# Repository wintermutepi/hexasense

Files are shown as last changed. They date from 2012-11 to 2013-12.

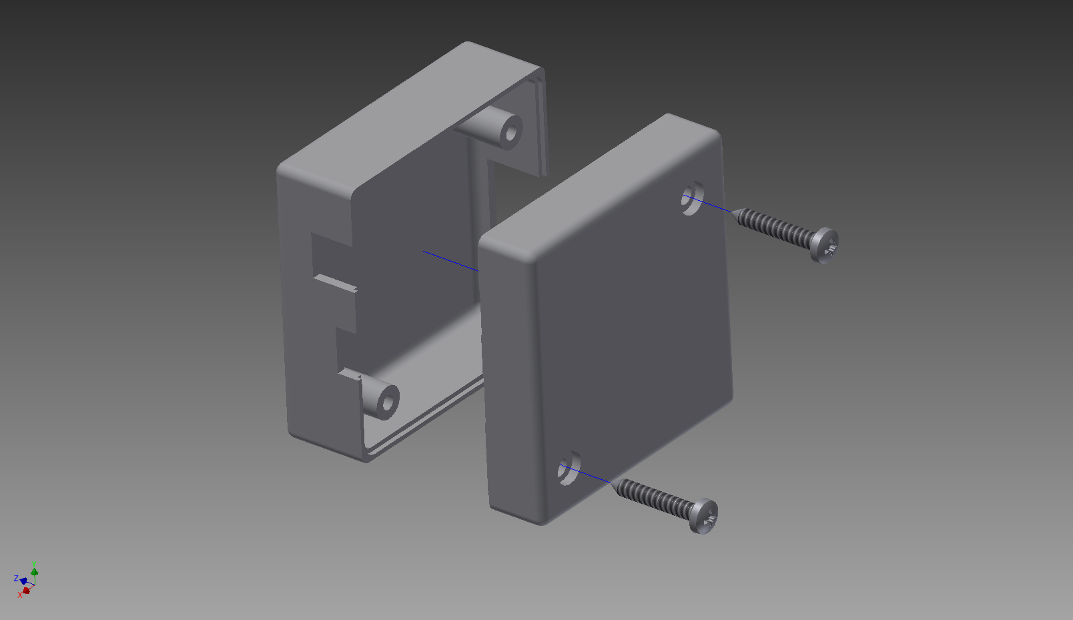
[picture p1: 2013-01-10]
enclosure/power_board/Assembly1.png

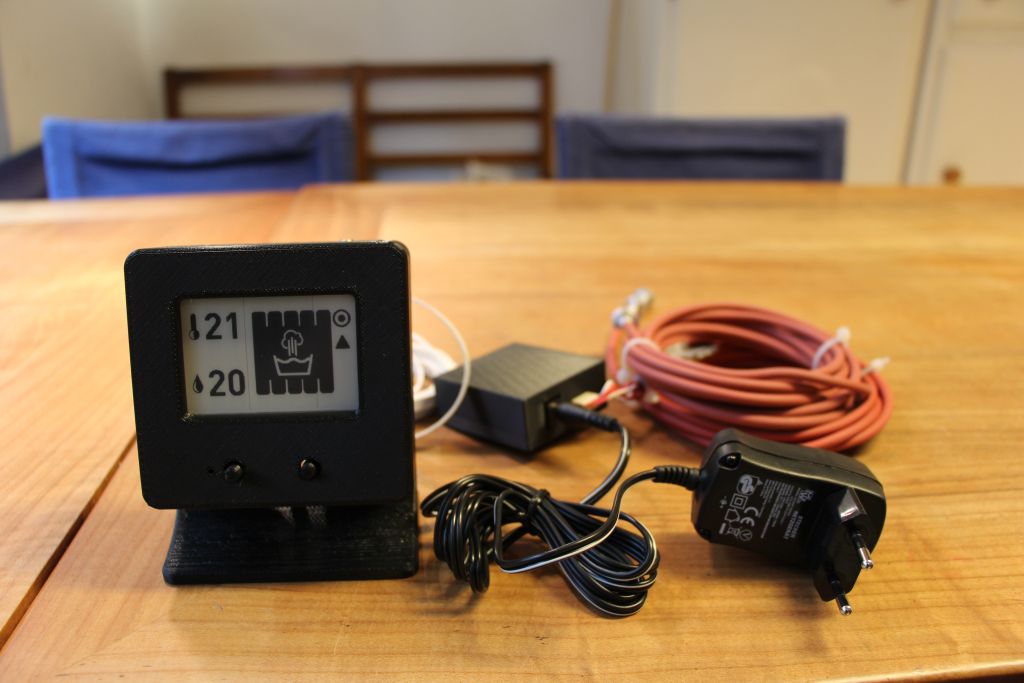
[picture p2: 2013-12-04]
doc/IMG_2463_.jpg

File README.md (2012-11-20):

HexaSense
=========

This is a prototyping project for a room heating controller based on the
HexaBus architecture. Nothing spectacular to see here - this is just a
playground.

### License

The UART code is written by Peter Fleury. Everything else: BSD 2-clause
license as below:

Copyright (c) 2012, Mathias Dalheimer
All rights reserved.

Redistribution and use in source and binary forms, with or without
modification, are permitted provided that the following conditions are
met:

* Redistributions of source code must retain the above copyright notice, 
this list of conditions and the following disclaimer.

* Redistributions in binary form must reproduce the above copyright
notice, this list of conditions and the following disclaimer in the
documentation and/or other materials provided with the distribution.

THIS SOFTWARE IS PROVIDED BY THE COPYRIGHT HOLDERS AND CONTRIBUTORS "AS
IS" AND ANY EXPRESS OR IMPLIED WARRANTIES, INCLUDING, BUT NOT LIMITED
TO, THE IMPLIED WARRANTIES OF MERCHANTABILITY AND FITNESS FOR A
PARTICULAR PURPOSE ARE DISCLAIMED. IN NO EVENT SHALL THE COPYRIGHT
HOLDER OR CONTRIBUTORS BE LIABLE FOR ANY DIRECT, INDIRECT, INCIDENTAL,
SPECIAL, EXEMPLARY, OR CONSEQUENTIAL DAMAGES (INCLUDING, BUT NOT
LIMITED TO, PROCUREMENT OF SUBSTITUTE GOODS OR SERVICES; LOSS
OF USE, DATA, OR PROFITS; OR BUSINESS INTERRUPTION) HOWEVER
CAUSED AND ON ANY THEORY OF LIABILITY, WHETHER IN CONTRACT,
STRICT LIABILITY, OR TORT (INCLUDING NEGLIGENCE OR OTHERWISE)
ARISING IN ANY WAY OUT OF THE USE OF THIS SOFTWARE, EVEN IF ADVISED OF
THE POSSIBILITY OF SUCH DAMAGE.

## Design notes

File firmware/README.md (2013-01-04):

### HexaSense

TODO: Description & foo.

### TODOs

* Implement fake LED driver: Just dump the LED status over the serial
  line as long as the real hardware is not available.
* Implement device logic.
* Implement standalone heuristics.
* Port to hexabus.

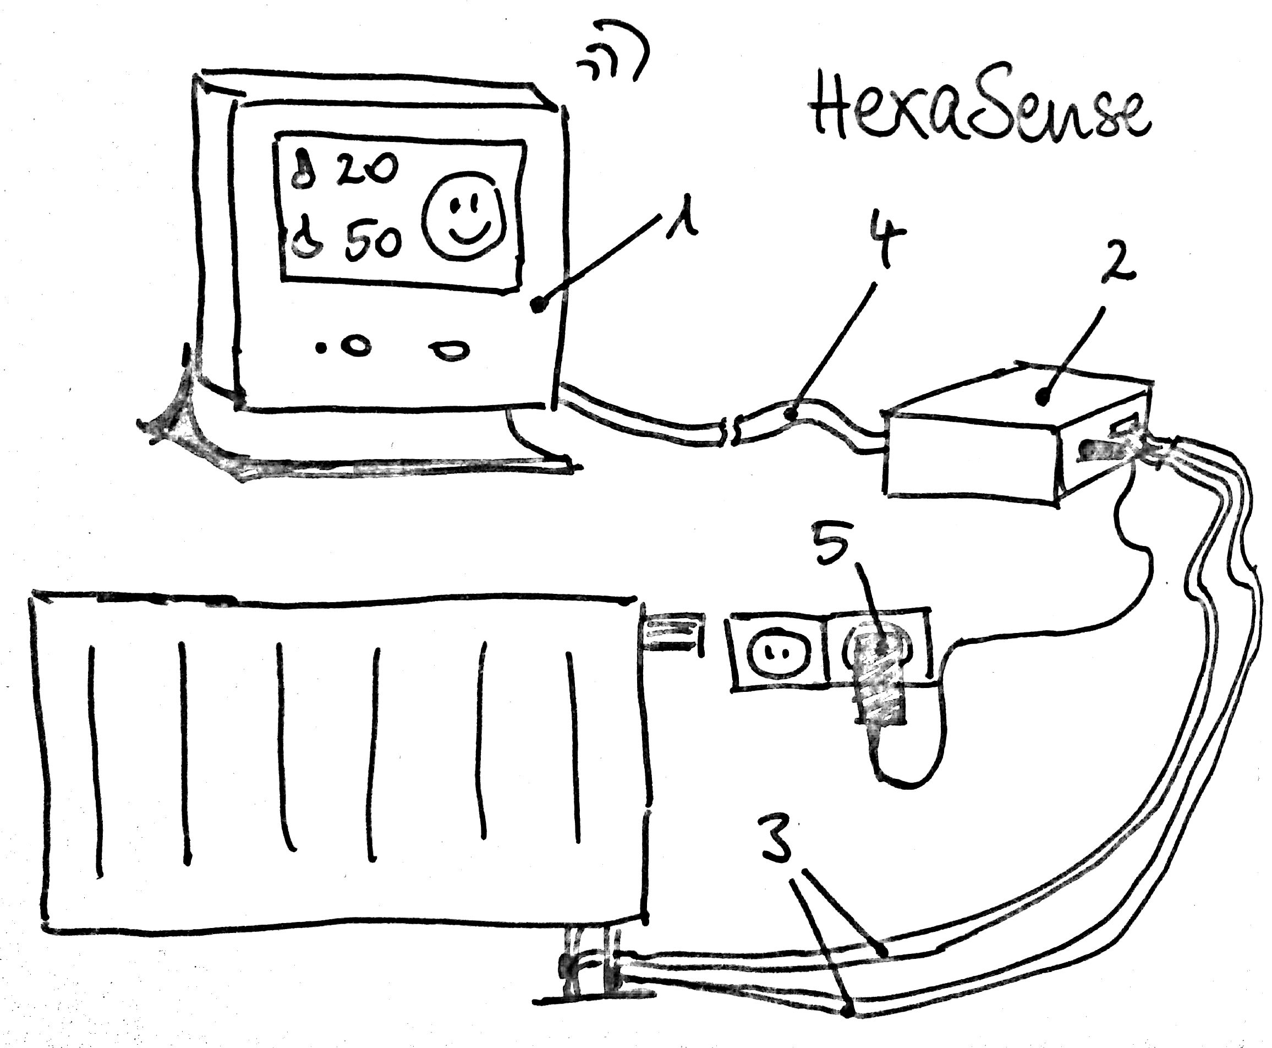
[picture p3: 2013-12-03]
doc/Hexasense3.jpg

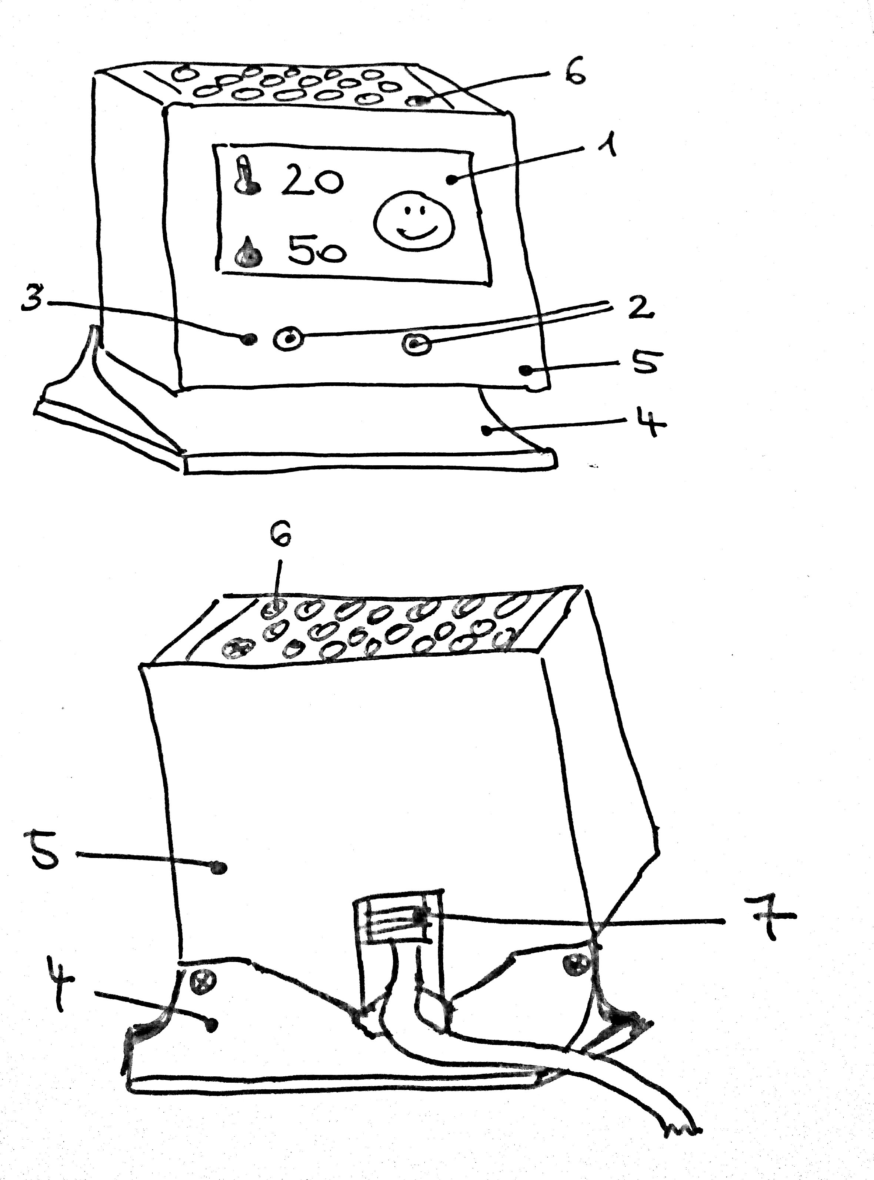
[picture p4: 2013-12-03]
doc/Hexasense1.jpg

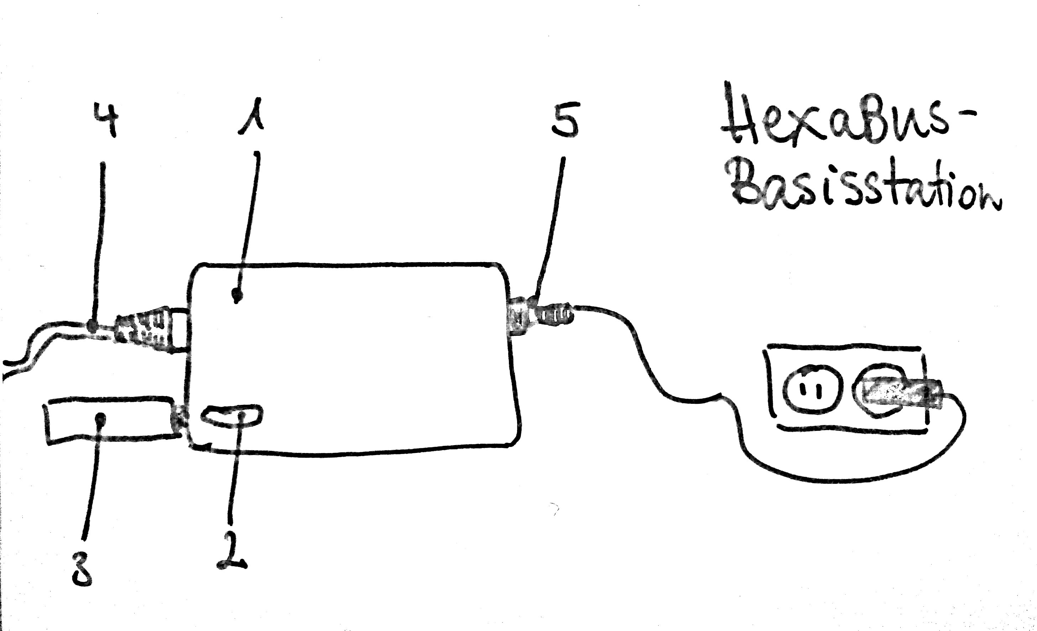
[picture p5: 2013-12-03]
doc/Hexasense2.jpg

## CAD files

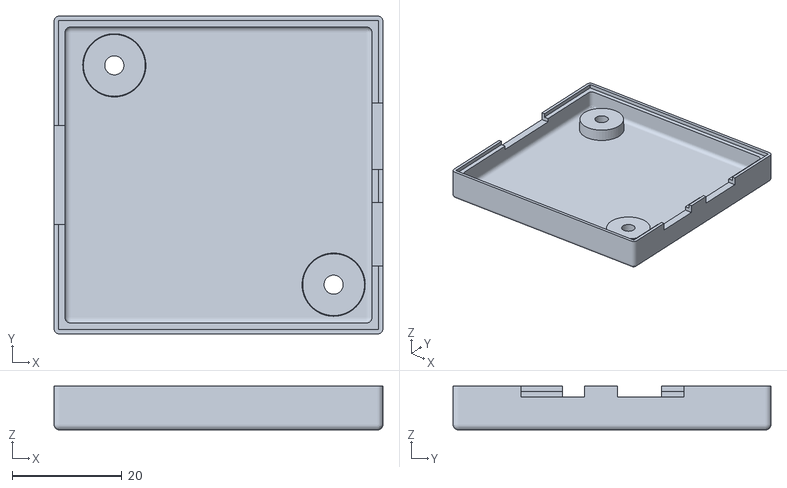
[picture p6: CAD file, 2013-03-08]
enclosure/power_board/Unterschale2.stl
60.0 x 58.0 x 8.00

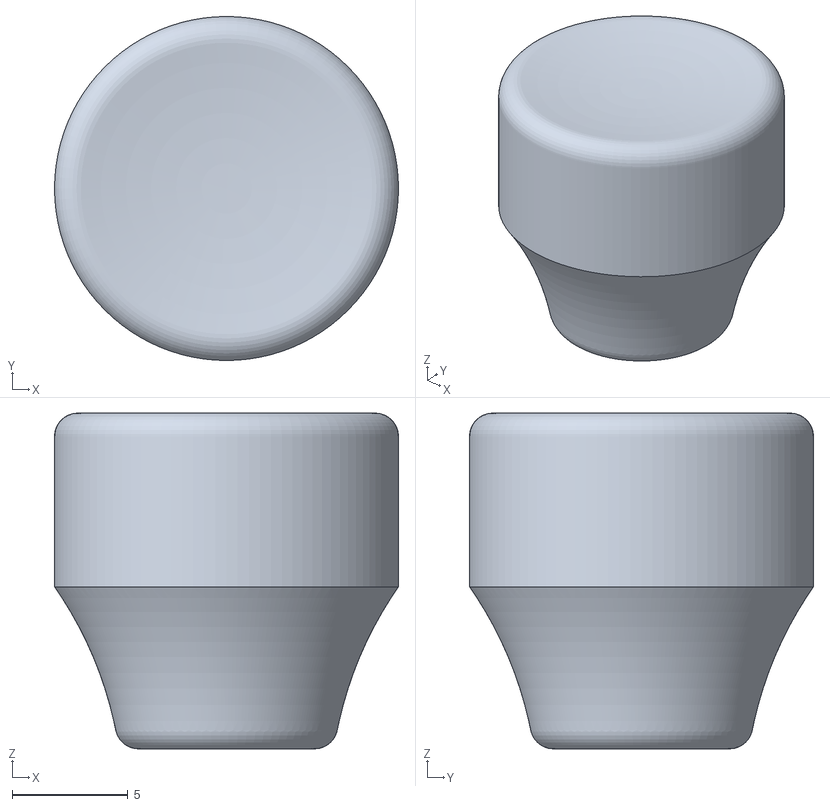
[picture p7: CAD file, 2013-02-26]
enclosure/sense_board/pushbutton.stl
14.9 x 14.9 x 14.5

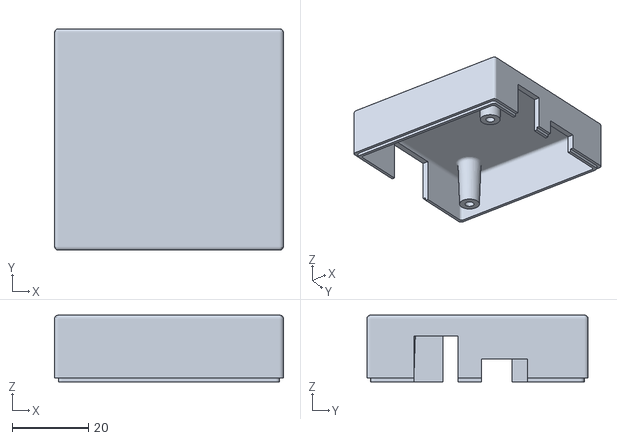
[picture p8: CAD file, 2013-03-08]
enclosure/power_board/Oberschale2.stl
60.0 x 58.0 x 17.5

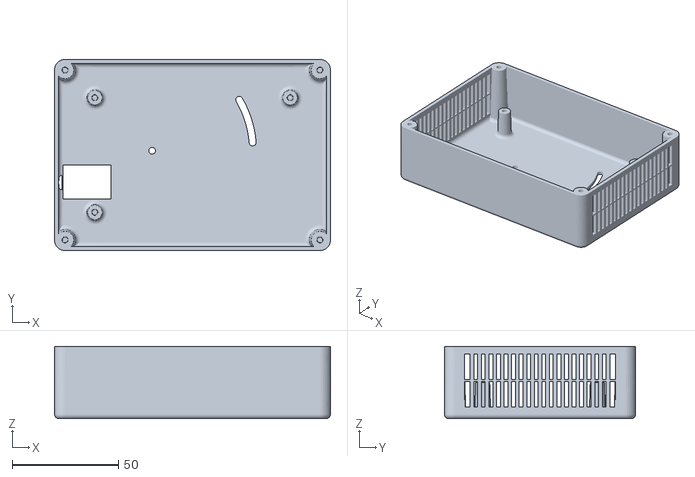
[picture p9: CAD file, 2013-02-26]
enclosure/sense_board/base.stl
130.0 x 90.0 x 34.0

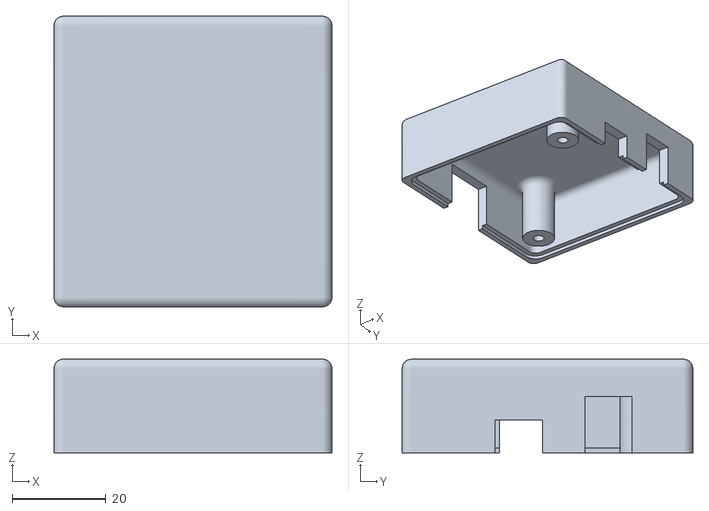
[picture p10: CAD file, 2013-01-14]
enclosure/power_board/Oberschale.stl
59.3 x 62.0 x 20.0

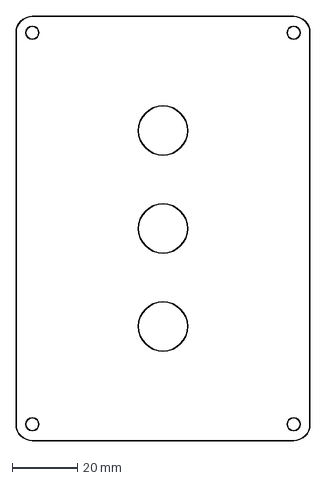
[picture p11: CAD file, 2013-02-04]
enclosure/sense_board/frontplatte.dxf
90.0 x 130.0 mm

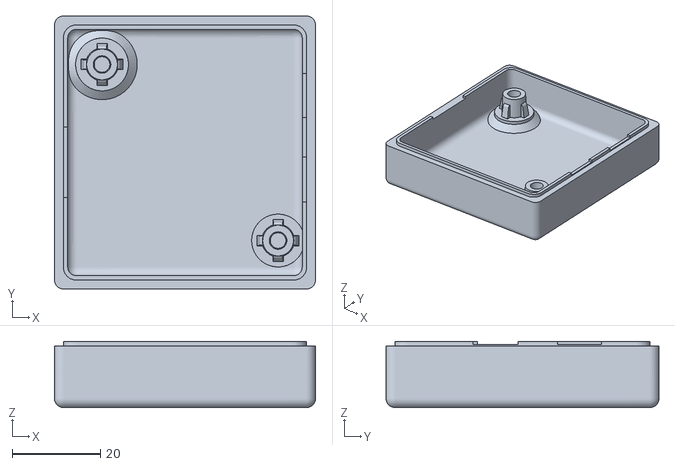
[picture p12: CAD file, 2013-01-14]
enclosure/power_board/Unterschale.stl
59.3 x 62.0 x 15.0

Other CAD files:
enclosure/power_board/Assembly1.iam
enclosure/power_board/Assembly1.ipn
enclosure/power_board/Assembly2.iam
enclosure/power_board/Oberschale.ipt
enclosure/power_board/Oberschale2.ipt
enclosure/power_board/OldVersions/Enclosure-bottom.0001.ipt
enclosure/power_board/OldVersions/enclosure1.0007.ipt
enclosure/power_board/PCB-Model.ipt
enclosure/power_board/Unterschale.ipt
enclosure/power_board/Unterschale2.ipt
enclosure/sense_board/Assembly1.iam
enclosure/sense_board/PCB-Model.ipt
enclosure/sense_board/base.ipt
enclosure/sense_board/frontplatte.dwg
enclosure/sense_board/frontplatte.ipt
enclosure/sense_board/pushbutton.ipt

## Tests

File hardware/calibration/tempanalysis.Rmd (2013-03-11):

Temperature sensor calibration
========================================================

```{r loaddata, cache=TRUE}
foo=read.table("data/20130311-no-lights.txt", sep=";");
logdata=data.frame(
  idx=c(1:length(foo$V1)),
  t_hyt=foo$V1,
  h_hyt=foo$V2,
  t_an1=foo$V4,
  t_an2=foo$V5
  )
mintemp=min(logdata$t_hyt, logdata$t_an1, logdata$t_an2)
maxtemp=max(logdata$t_hyt, logdata$t_an1, logdata$t_an2)
tmpframe=data.frame(logdata$t_an1, logdata$t_an2);
t_mean_analog = rowMeans(tmpframe);
```

# Visual inspection of dataset

```{r visual, dependson="loaddata", cache=TRUE, fig.width=7, fig.height=6}
plot(logdata$idx, logdata$t_hyt, type="l", col=1, xlab="Index", 
     ylab="Temperature [deg C]", ylim=c(mintemp, maxtemp));
lines(logdata$idx, logdata$t_an1, type="l", col=2);
lines(logdata$idx, logdata$t_an2, type="l", col=3);
legend(3000, 26.2, c("HYT271", "Analog 1", "Analog 2"), col=c(1:3), lty=1)
```

```{r summary, dependson="loaddata"}
summary(logdata)
```

# Fitting a linear model

Assumption: The real temperature is the mean of the two analog temperature sensors.
TODO: Ensure proper calibration of both sensors.

```{r linmodel, dependson="loaddata", cache=TRUE}
lm1 = lm(logdata$t_hyt ~ t_mean_analog)
summary(lm1)
plot(lm1)
cat(paste("The offset of the linear model is ", lm1$coefficients[1]))
```

## Using loess to smoothen values.
The t_mean_analog factor seems odd - this should be one. Hypothesis: The discretization of the sensor values interferes with the model. 

```{r smooth, dependson="loaddata", cache=TRUE}
loess_hyt=loess(logdata$t_hyt ~ logdata$idx, span=0.1)
plot(logdata$idx, logdata$t_hyt, type="o", col=1, xlab="Index", 
     ylab="Temperature [deg C]", ylim=c(mintemp, maxtemp), pch=19, cex=0.2);
lines(logdata$idx, loess_hyt$fitted, type="l", col=3, cex=10);

loess_analog=loess(t_mean_analog ~ logdata$idx, span=0.1)
lines(logdata$idx, t_mean_analog, type="o", col=2, pch=19, cex=0.2);
lines(logdata$idx, loess_analog$fitted, type="l", col=3, cex=2);
legend(3000, 26.2, c("HYT271", "Analog Mean"), col=c(1:2), lty=1)
lm3=lm(loess_hyt$fitted ~ loess_analog$fitted)
summary(lm3)
qqplot(logdata$t_hyt, t_mean_analog)
abline(c(lm3$coeff[1], 1))
```

## FOo0

```{r foo, dependson="loaddata"}
s_t_hyt = sort(logdata$t_hyt)
s_t_analog= sort(t_mean_analog)
lm4=lm(s_t_hyt ~ s_t_analog)
summary(lm4)
qqplot(logdata$t_hyt, t_mean_analog)
abline(c(abs(lm4$coeff[1]), 1))
```

## Using simpler median statistics 

```{r median, dependson="loaddata", cache=TRUE}
m_hyt=quantile(logdata$t_hyt, probs=0.5)
m_analog=quantile(t_mean_analog, probs=0.5)
offset = m_analog - m_hyt
cat(paste("The offset between HYT and the mean analog sensor is ", offset))
qqplot(logdata$t_hyt, t_mean_analog)
abline(c(offset, 1))
```

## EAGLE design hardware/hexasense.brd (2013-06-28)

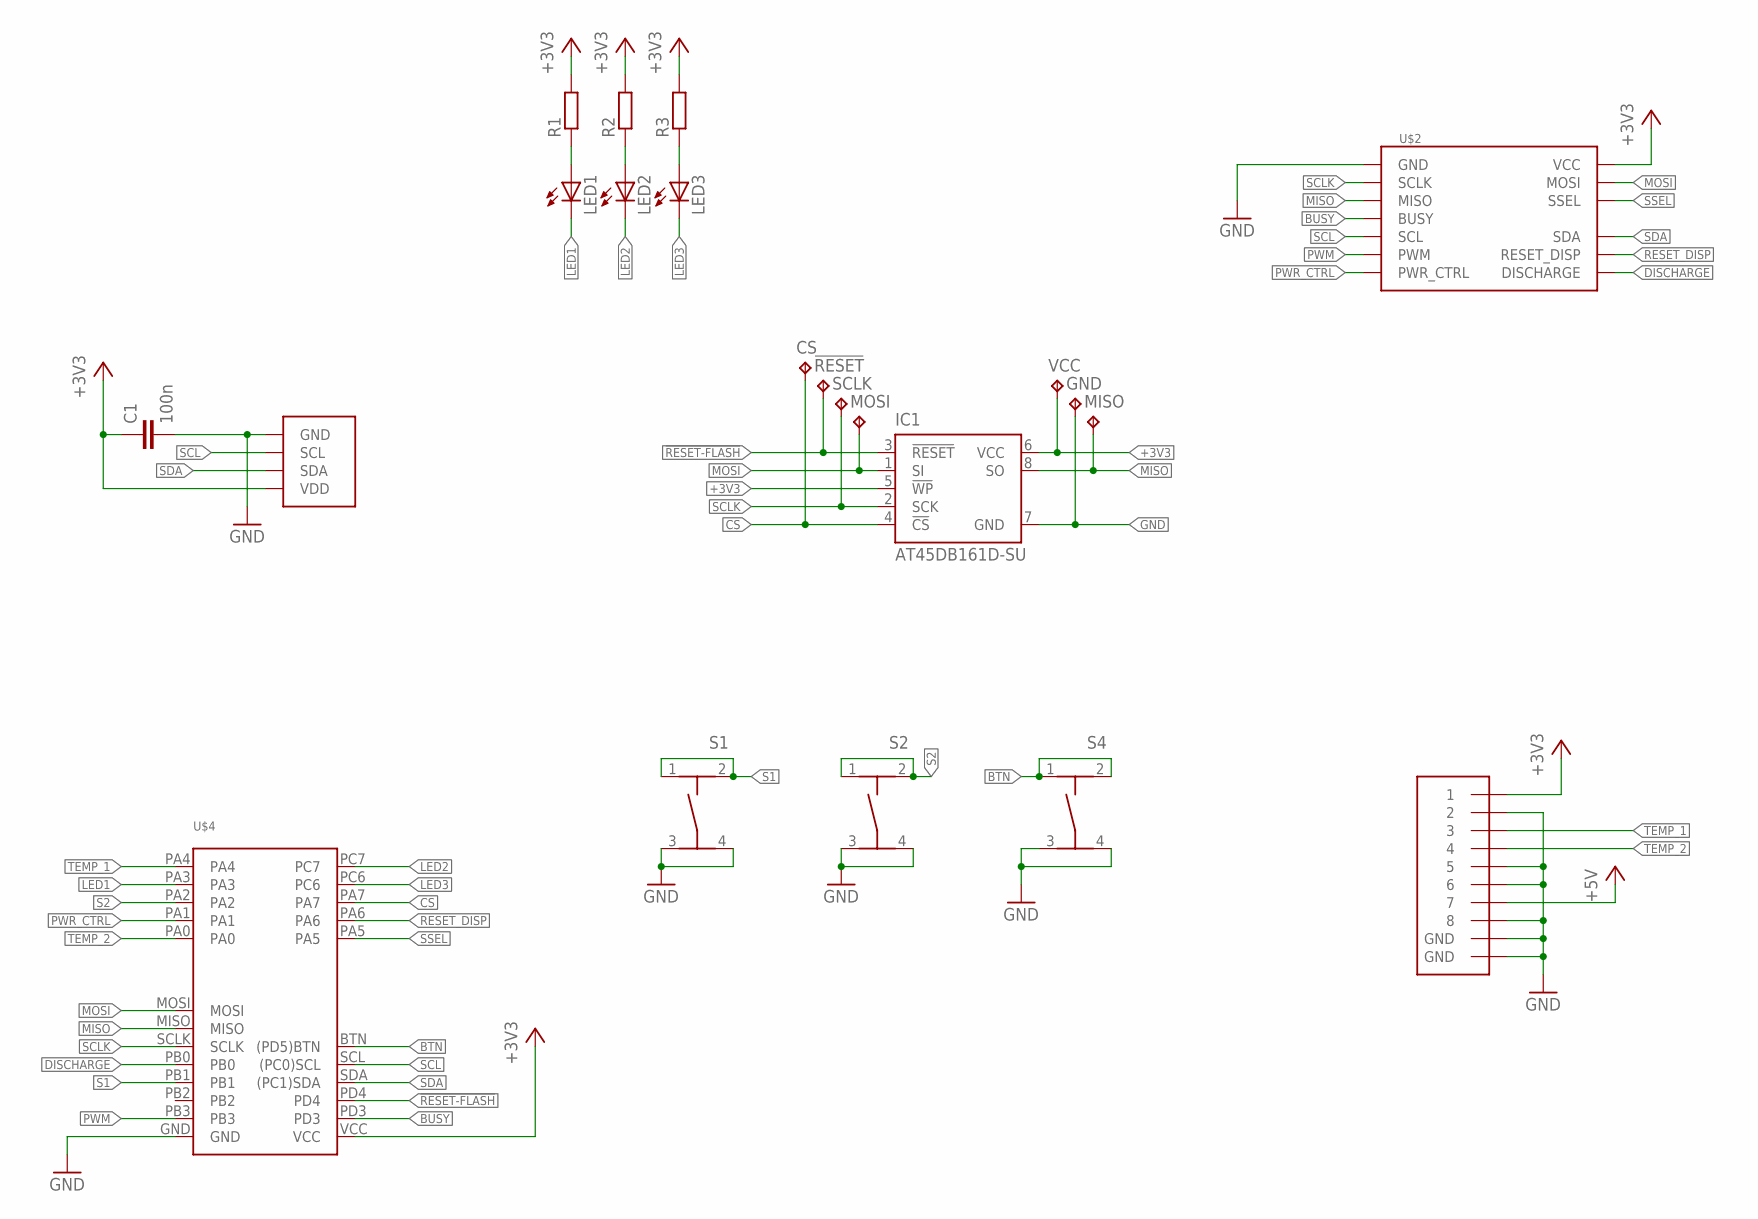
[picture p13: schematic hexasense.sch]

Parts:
!RESET: TPB1,27; B1,27
C1: 100n; C0805
CS: TPB1,27; B1,27
GND: TPB1,27; B1,27
IC1: AT45DB161D-SU; 8S2
LED1, LED2, LED3: LED3MM
MISO: TPB1,27; B1,27
MOSI: TPB1,27; B1,27
R1, R2, R3: R-EU_R0805; R0805
S1, S2, S4: TASTER-9314_SMD
SCLK: TPB1,27; B1,27
U$1: MEBP8-8G; RJ45-REICHELT
U$2: EPAPER
U$4: HEXABUS
U$7: HYT271
VCC: TPB1,27; B1,27

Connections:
!RESET-FLASH: !RESET.TP, IC1.3 (!RESET), U$4.PD4
+3V3: C1.1, IC1.5 (!WP), IC1.6 (VCC), R1.2, R2.2, R3.2, U$1.1, U$2.P2 (VCC), U$4.VCC, U$7.VDD, VCC.TP
+5V: U$1.7
BTN: S4.1, S4.2, U$4.BTN ((PD5)BTN)
BUSY: U$2.P7 (BUSY), U$4.PD3
CS: CS.TP, IC1.4 (!CS), U$4.PA7
DISCHARGE: U$2.P14 (DISCHARGE), U$4.PB0
GND: C1.2, GND.TP, IC1.7 (GND), S1.3, S1.4, S2.3, S2.4, S4.3, S4.4, U$1.2, U$1.5, U$1.6, U$1.8, U$1.GND@1 (GND), U$1.GND@2 (GND), U$2.P1 (GND), U$4.GND, U$7.GND
LED1: LED1.K (C), U$4.PA3
LED2: LED2.K (C), U$4.PC7
LED3: LED3.K (C), U$4.PC6
MISO: IC1.8 (SO), MISO.TP, U$2.P5 (MISO), U$4.MISO
MOSI: IC1.1 (SI), MOSI.TP, U$2.P4 (MOSI), U$4.MOSI
unnamed: LED3.A, R3.1
unnamed: LED2.A, R2.1
unnamed: LED1.A, R1.1
PWM: U$2.P11 (PWM), U$4.PB3
PWR_CTRL: U$2.P13 (PWR_CTRL), U$4.PA1
RESET_DISP: U$2.P12 (RESET_DISP), U$4.PA6
S1: S1.1, S1.2, U$4.PB1
S2: S2.1, S2.2, U$4.PA2
SCL: U$2.P9 (SCL), U$4.SCL ((PC0)SCL), U$7.SCL
SCLK: IC1.2 (SCK), SCLK.TP, U$2.P3 (SCLK), U$4.SCLK
SDA: U$2.P10 (SDA), U$4.SDA ((PC1)SDA), U$7.SDA
SSEL: U$2.P6 (SSEL), U$4.PA5
TEMP_1: U$1.3, U$4.PA4
TEMP_2: U$1.4, U$4.PA0

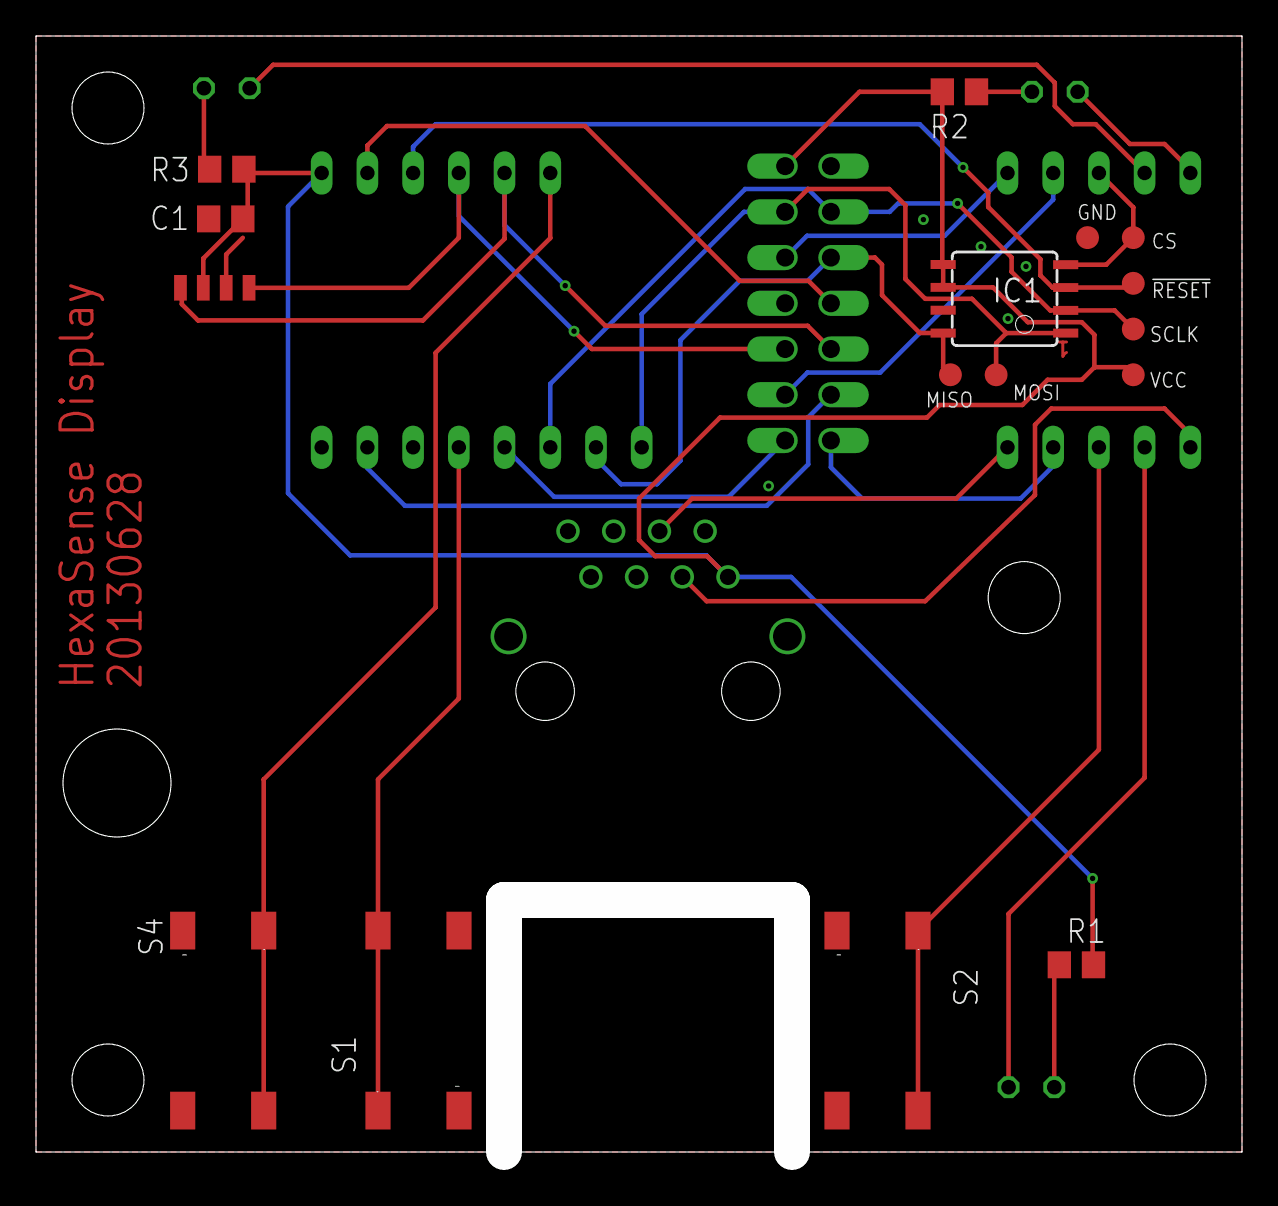
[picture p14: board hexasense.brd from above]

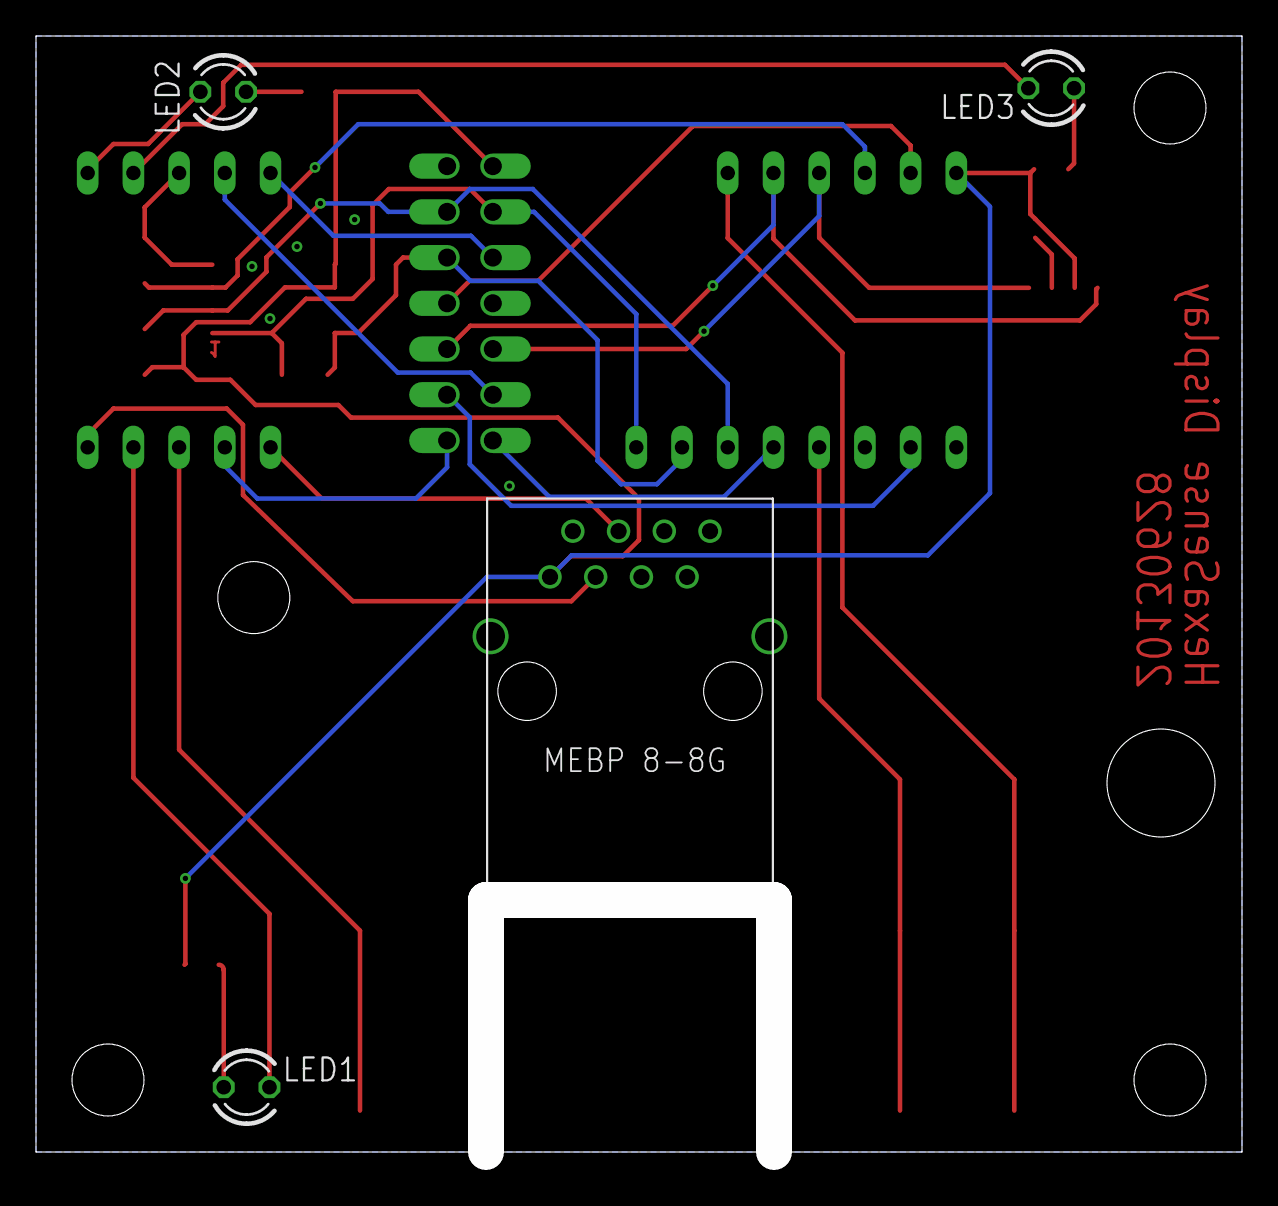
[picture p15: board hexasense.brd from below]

Board: 2 copper layers, 67.0 x 62.0 mm, 22 parts (5 on the bottom side), 26 nets.

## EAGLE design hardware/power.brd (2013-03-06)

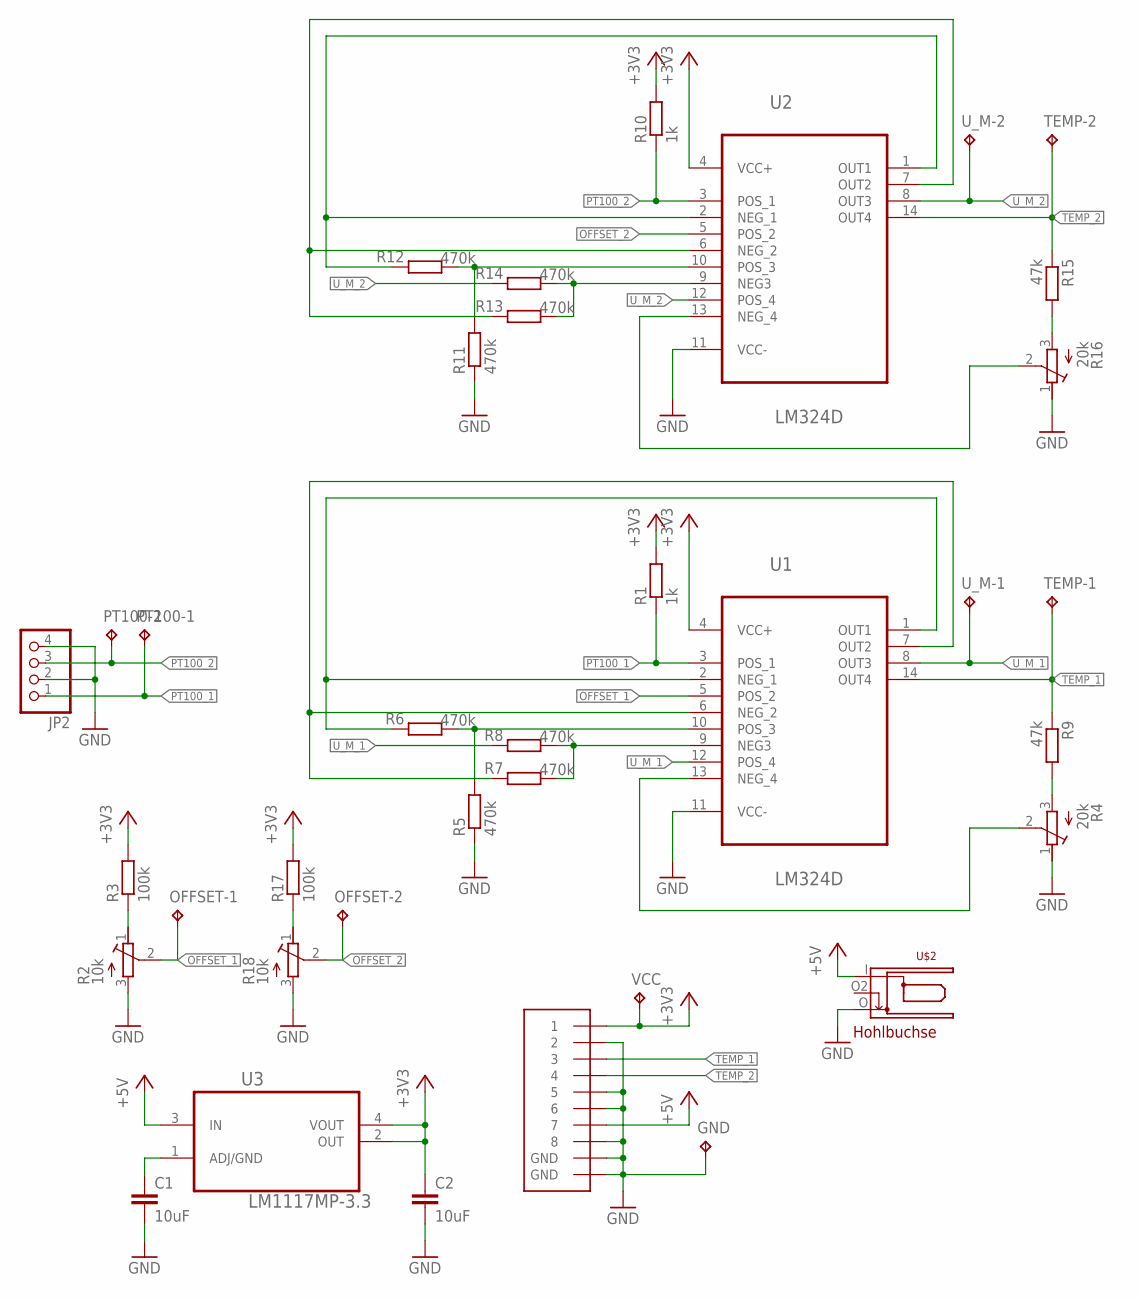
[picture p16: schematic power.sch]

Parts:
C1, C2: 10uF; C0805
GND: TPPAD1-13; P1-13
JP2: PINHD-1X4/90; 1X04/90
OFFSET-1, OFFSET-2: TPPAD1-13; P1-13
PT100-1, PT100-2: TPPAD1-13; P1-13
R1, R10: 1k; R0805
R2, R18: 10k; RTRIMT93YB
R3, R17: 100k; R0805
R4, R16: 20k; RTRIMT93YB
R5, R6, R7, R8, R11, R12, R13, R14: 470k; R0805
R9, R15: 47k; R0805
TEMP-1, TEMP-2: TPPAD1-13; P1-13
U1, U2: LM324D; SOIC127P600X175-14N
U3: LM1117MP-3.3; SOT230P696X180-4N
U$1: MEBP8-8G; RJ45-REICHELT
U$2: HOHLBUCHSE
U_M-1, U_M-2: TPPAD1-13; P1-13
VCC: TPPAD1-13; P1-13

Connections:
+3V3: C2.1, R1.2, R3.2, R10.2, R17.2, U1.4 (VCC+), U2.4 (VCC+), U3.2 (OUT), U3.4 (VOUT), U$1.1, VCC.TP
+5V: U3.3 (IN), U$1.7, U$2.I
GND: C1.2, C2.2, GND.TP, JP2.2, JP2.4, R2.3 (A), R4.1 (E), R5.1, R11.1, R16.1 (E), R18.3 (A), U1.11 (VCC-), U2.11 (VCC-), U$1.2, U$1.5, U$1.6, U$1.8, U$1.GND@1 (GND), U$1.GND@2 (GND), U$2.O
unnamed: R4.2 (S), U1.13 (NEG_4)
unnamed: R5.2, R6.1, U1.10 (POS_3)
unnamed: R2.1 (E), R3.1
unnamed: R15.2, R16.3 (A)
unnamed: R6.2, U1.1 (OUT1), U1.2 (NEG_1)
unnamed: R16.2 (S), U2.13 (NEG_4)
unnamed: R7.2, U1.6 (NEG_2), U1.7 (OUT2)
unnamed: R7.1, R8.1, U1.9 (NEG3)
unnamed: R11.2, R12.1, U2.10 (POS_3)
unnamed: R12.2, U2.1 (OUT1), U2.2 (NEG_1)
unnamed: R4.3 (A), R9.2
unnamed: R13.2, U2.6 (NEG_2), U2.7 (OUT2)
unnamed: R13.1, R14.1, U2.9 (NEG3)
unnamed: R17.1, R18.1 (E)
unnamed: C1.1, U3.1 (ADJ/GND)
OFFSET_1: OFFSET-1.TP, R2.2 (S), U1.5 (POS_2)
OFFSET_2: OFFSET-2.TP, R18.2 (S), U2.5 (POS_2)
PT100_1: JP2.1, PT100-1.TP, R1.1, U1.3 (POS_1)
PT100_2: JP2.3, PT100-2.TP, R10.1, U2.3 (POS_1)
TEMP_1: R9.1, TEMP-1.TP, U1.14 (OUT4), U$1.3
TEMP_2: R15.1, TEMP-2.TP, U2.14 (OUT4), U$1.4
U_M_1: R8.2, U1.8 (OUT3), U1.12 (POS_4), U_M-1.TP
U_M_2: R14.2, U2.8 (OUT3), U2.12 (POS_4), U_M-2.TP

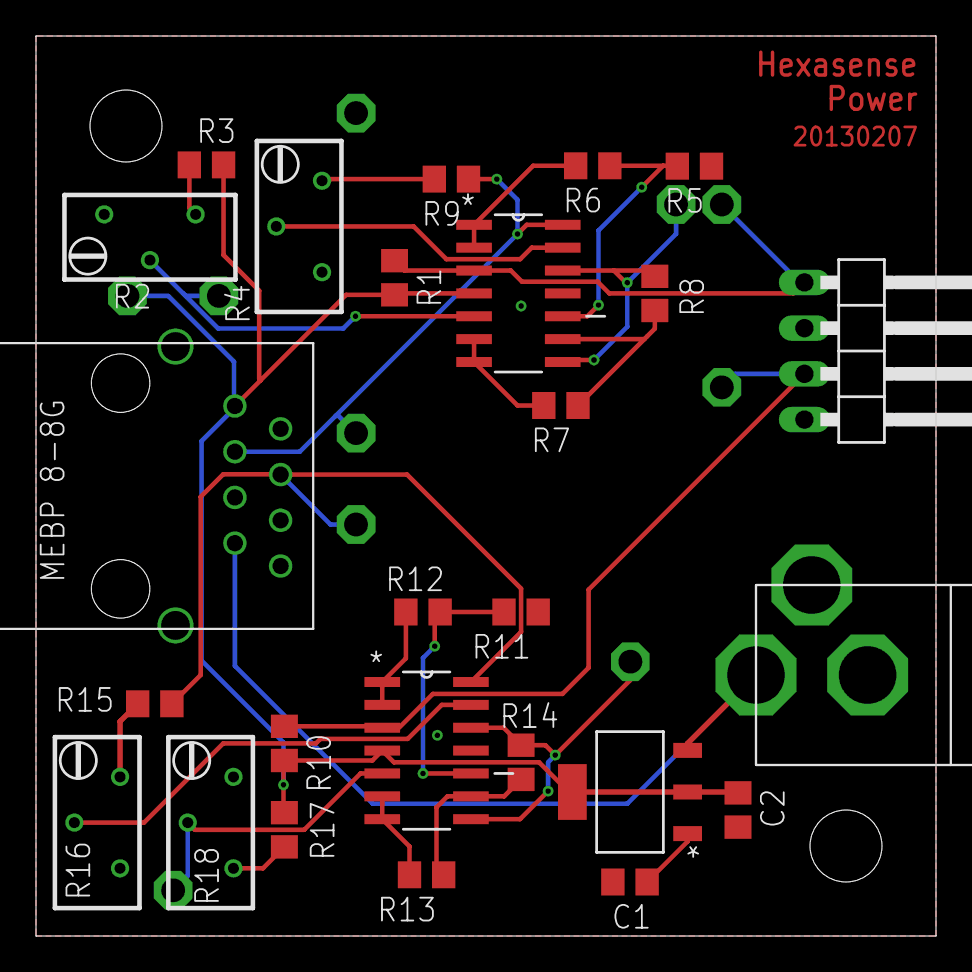
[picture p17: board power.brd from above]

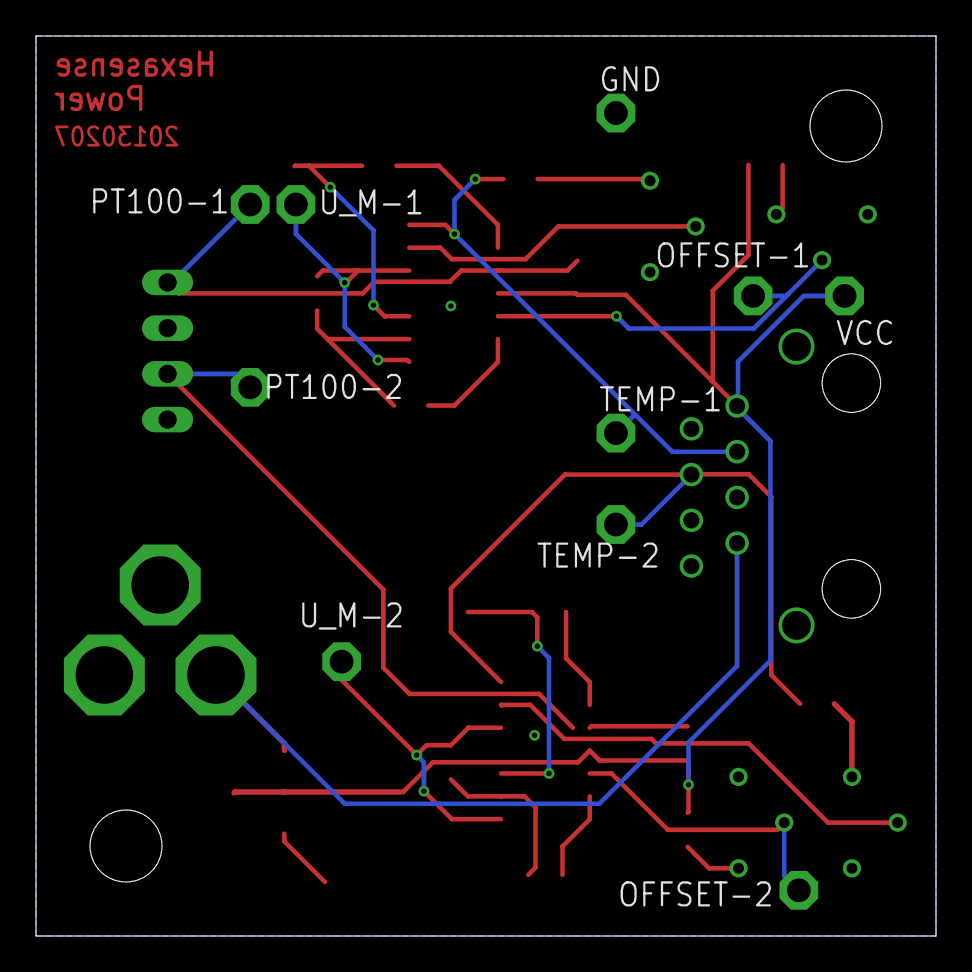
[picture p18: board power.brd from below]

Board: 2 copper layers, 50.0 x 50.0 mm, 36 parts (10 on the bottom side), 26 nets.

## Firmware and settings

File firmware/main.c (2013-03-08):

#include <stdlib.h>
#include <stdbool.h>
#include <avr/io.h>
#include <util/delay.h>
#include <avr/interrupt.h>
#include <avr/pgmspace.h>

#include "uart.h"
#include "adc.h"
#include "dht_sensor.h"
#include "dew_point.h"
#include "hyt271.h"
#include "button.h"
#include "led_driver.h"
#include "adc_temp_conversion.h"
#include "i2cmaster.h"

/* define CPU frequency in Mhz here if not defined in Makefile */
#ifndef F_CPU
#define F_CPU 8000000UL
#endif

/* 9600 baud */
#define UART_BAUD_RATE      9600      

/**
 * this firmware has two modi: 
 * (1) button-triggered operation: meant for post-production testing
 * (2) stress-testing: for long-time hardware testing.
 * Define STRESS_TEST to select (2), (1) is default.
 */
#define STRESS_TEST 1

void init(void) {
  /*
   *  Initialize UART library, pass baudrate and AVR cpu clock
   *  with the macro 
   *  UART_BAUD_SELECT() (normal speed mode )
   *  or 
   *  UART_BAUD_SELECT_DOUBLE_SPEED() ( double speed mode)
   */
  uart_init( UART_BAUD_SELECT(UART_BAUD_RATE,F_CPU) ); 
  /*
   * now enable interrupt, since UART library is interrupt controlled
   */
  sei();

  uart_puts_P("HexaSense prototype startup\n\r");
  /**
   * run the initialization code of all components
   */
  adc_init();
  button_init();
  led_init();
  i2c_init();
}

void read_digital_sensors(void) {
  char buffer[7];
#ifndef STRESS_TEST
  uart_puts_P("HYT271 sensor:\r\n");
#endif
  double hyt271_hum = 0.0;
  double hyt271_temp = 0.0;
  HYT271_ERROR_t error_code =  hyt271_get_measurements(&hyt271_hum, &hyt271_temp);
  switch(error_code) {
	case HYT271_ERROR_NONE:
#ifndef STRESS_TEST
	  uart_puts_P("Temperature: ");
#endif
	  dtostrf(hyt271_temp, 5, 2, buffer);   // convert interger into string (decimal format)         
	  uart_puts(buffer);        // and transmit string to UART
#ifndef STRESS_TEST
	  uart_puts_P("\r\nHumidity: ");
#else
	  uart_puts_P(";");
#endif
	  itoa(hyt271_hum, buffer, 10);   // convert interger into string (decimal format)         
	  uart_puts(buffer);        // and transmit string to UART
#ifndef STRESS_TEST
	  uart_puts_P("\r\n");
	  uart_puts_P("Dewpoint based on HYT271 sensor: ");
#else
	  uart_puts_P(";");
#endif
	  double dp=dew_point(hyt271_temp, hyt271_hum);
	  itoa(dp, buffer, 10);   // convert interger into string (decimal format)         
	  uart_puts(buffer);        // and transmit string to UART
#ifndef STRESS_TEST
	  uart_puts_P("\r\n");
#else
	  uart_puts_P(";");
#endif
	  break;
	case HYT271_BUS_ERROR:
	  uart_puts_P("Bus error while reading HYT271 sensor.\r\n");
	  break;
	default:
	  uart_puts_P("Unknown error reading HYT271 sensor.\r\n");
	  break;
  }
}

void read_analog_sensor(void) {
  float temperature1=temperature_adc(0); // convert from adc value to temperaure 
  float temperature2=temperature_adc(4); // convert from adc value to temperaure 
#ifndef STRESS_TEST
  uart_puts_P("Temperature from ADC0: ");
#endif
  char temperature_string_buffer[10];
  dtostrf(temperature1, 5,2, temperature_string_buffer);   // convert interger into string (decimal format)         
  uart_puts(temperature_string_buffer);        // and transmit string to UART
#ifndef STRESS_TEST
  uart_puts_P("\r\n");
#else
	  uart_puts_P(";");
#endif
#ifndef STRESS_TEST
  uart_puts_P("Temperature from ADC4: ");
#endif
  dtostrf(temperature2, 5,2, temperature_string_buffer);   // convert interger into string (decimal format)         
  uart_puts(temperature_string_buffer);        // and transmit string to UART
#ifndef STRESS_TEST
  uart_puts_P("\r\n");
#else
	  uart_puts_P(";");
#endif
}

void button_loop(void) {
  enum led_states {
	LED_OFF = 0,
	LED_ALL = 1,
	LED_RED = 2,
	LED_GREEN = 3,
	LED_BLUE = 4
  };
  enum led_states statemachine;
  statemachine=LED_OFF;
  led_all_off();
  while(1) {
	if (is_button0_pressed()) {
	  uart_puts_P("BTN0 pressed.\r\n");
	  read_digital_sensors();
	}
	if (is_button1_pressed()) {
	  uart_puts_P("BTN1 pressed.\r\n");
	  read_analog_sensor();
	}
	if (is_button2_pressed()) {
	  uart_puts_P("BTN2 pressed.\r\n");
	  switch (statemachine) {
		case LED_OFF: led_all_full(); statemachine = LED_ALL; break;
		case LED_ALL: led_red_full(); statemachine = LED_RED; break;
		case LED_RED: led_green_full(); statemachine = LED_GREEN; break;
		case LED_GREEN: led_blue_full(); statemachine = LED_BLUE; break;
		case LED_BLUE: led_all_off(); statemachine = LED_OFF; break;
	  }
	}
  }
}

void stress_test(void) {
  led_all_full(); 
  while(1) {
	read_digital_sensors();
	read_analog_sensor();
	uart_puts_P("\r\n");
	_delay_ms(60000);
  }
}

int main(void)
{
  init();

  // For debugging. Do not use in production.
  //// LED1: On PC7, active low.
  //DDRC |= (1 << PC7);
  //PORTC &= ~(1 << PC7);

#ifndef STRESS_TEST
  button_loop();
#else
  stress_test();
#endif

}

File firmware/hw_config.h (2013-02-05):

#ifndef HW_CONFIG_H
#define HW_CONFIG_H 1

/**
 * Connection of the DHT22 sensor.
 */
#define DHT22_PIN    PD3
#define DHT22_PORT   PORTD
#define DHT22_DDR    DDRD
#define DHT22_PINC   PIND


/**
 * Connection of the first button: PA1
 */
#define BTN0_DDR	DDRA
#define BTN0_PORT	PORTA
#define BTN0_PIN	PA1
#define BTN0_IN		PINA

/**
 * Connection of the second button: PA2
 */
#define BTN1_DDR	DDRA
#define BTN1_PORT	PORTA
#define BTN1_PIN	PA2
#define BTN1_IN		PINA

/**
 * Connection of the third button: PA3
 */
#define BTN2_DDR	DDRA
#define BTN2_PORT	PORTA
#define BTN2_PIN	PA3
#define BTN2_IN		PINA

/**
 * I2C error codes.
 */
#define I2C_ERROR 1
#define I2C_SUCCESS 0

/**
 * PCA9532 I2C bus definitions
 */
#define PCA9532_ADDR  0xC0
#define PCA9532_FULL 0x55
#define PCA9532_OFF 0x00

/**
 * HYT271 I2C bus definitions
 */

#define HYT271_ADDR (0x28 << 1)
#define HYT271_CONV_DELAY 6
#define HYT271_BUFFER_LEN 4

#endif /* HW_CONFIG_H */

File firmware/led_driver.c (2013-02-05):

#include "led_driver.h"
#include <avr/pgmspace.h>
#include "uart.h"
#include "i2cmaster.h"
#include "hw_config.h"


void led_init(void) {
  uart_puts_P("initializing LED driver\r\n");
  if (set_pca9532(
		0x00, // prescaler 0: maximum frequency
		0xFF, // pwm0: 256/256
		0x00, // prescaler 1: maximum frequency
		0xFF, // pwm1: 256/256
		PCA9532_OFF, // LED0-3: off.
		PCA9532_OFF, // LED4-7: off.
		PCA9532_OFF, // LED8-11: off.
		PCA9532_OFF  // LED12-15: off.
	)) 
  {
	uart_puts_P("LED initialization failed.\r\n");
  }
}

uint8_t set_pca9532(
	uint8_t psc0,
	uint8_t pwm0,
	uint8_t psc1,
	uint8_t pwm1,
	uint8_t ls0,
	uint8_t ls1,
	uint8_t ls2,
	uint8_t ls3)
{
  //i2c_init();
  // start communication with PCA9535
  if (i2c_start(PCA9532_ADDR+I2C_WRITE)) {
    uart_puts_P("I2C: Failed to access device.\r\n");
    return I2C_ERROR;
  } else {
    // PSC0 subaddress + auto-increment
    i2c_write(0x12);
    // prescaler 0
    i2c_write(psc0);
    // pwm0 duty cycle
    i2c_write(pwm0);
    // prescaler 1
    i2c_write(psc1);
    // pwm1 duty cycle
    i2c_write(pwm1);
    // LED 0-3 
    i2c_write(ls0);
    // LED 4-7 
    i2c_write(ls1);
    // LED 8-11
    i2c_write(ls2);
    // LED 12-15 
    i2c_write(ls3);
  }
  i2c_stop();
  return I2C_SUCCESS;
}


void led_all_off(void) {
  if (set_pca9532(
        0x00, // prescaler 0: maximum frequency
        0xFF, // pwm0: 256/256
        0x00, // prescaler 1: maximum frequency
        0xFF, // pwm1: 256/256
        PCA9532_OFF, // LED0-3: off.
        PCA9532_OFF, // LED4-7: off.
        PCA9532_OFF, // LED8-11: off.
        PCA9532_OFF  // LED12-15: off.
        )) 
  {
    uart_puts_P("LED initialization failed.\r\n");
  }
}

void led_all_full(void) {
  if (set_pca9532(
        0x00, // prescaler 0: maximum frequency
        0xFF, // pwm0: 256/256
        0x00, // prescaler 1: maximum frequency
        0xFF, // pwm1: 256/256
        PCA9532_FULL, // LED0-3: on.
        PCA9532_FULL, // LED4-7: on.
        PCA9532_FULL, // LED8-11: on.
        PCA9532_FULL  // LED12-15: on.
        )) 
  {
    uart_puts_P("LED initialization failed.\r\n");
  }
}

void led_good(void) {
  uart_puts_P("LED good.\r\n");
}

void led_intermediate(void) {
  uart_puts_P("LED intermediate.\r\n");
}

void led_bad(void) {
  uart_puts_P("LED bad.\r\n");
}

void led_red_full(void) {
  if (set_pca9532(
        0x00, // prescaler 0: maximum frequency
        0xFF, // pwm0: 256/256
        0x00, // prescaler 1: maximum frequency
        0xFF, // pwm1: 256/256
        PCA9532_FULL, // LED0-3: on.
        PCA9532_OFF, // LED4-7: off.
        PCA9532_OFF, // LED8-11: off.
        PCA9532_OFF  // LED12-15: off.
        )) 
  {
    uart_puts_P("LED initialization failed.\r\n");
  }
}

void led_green_full(void) {
  if (set_pca9532(
        0x00, // prescaler 0: maximum frequency
        0xFF, // pwm0: 256/256
        0x00, // prescaler 1: maximum frequency
        0xFF, // pwm1: 256/256
        PCA9532_OFF,
        PCA9532_FULL,
        PCA9532_OFF,
        PCA9532_OFF
        )) 
  {
    uart_puts_P("LED initialization failed.\r\n");
  }
}

void led_blue_full(void) {
  if (set_pca9532(
        0x00, // prescaler 0: maximum frequency
        0xFF, // pwm0: 256/256
        0x00, // prescaler 1: maximum frequency
        0xFF, // pwm1: 256/256
        PCA9532_OFF,
        PCA9532_OFF,
        PCA9532_FULL,
        PCA9532_OFF
        )) 
  {
    uart_puts_P("LED initialization failed.\r\n");
  }
}



void led_window_open(void) {
  uart_puts_P("LED window open.\r\n");
}

void led_disconnected(void) {
  uart_puts_P("LED disconnected.\r\n");
}

void led_error(void) {
  uart_puts_P("LED error.\r\n");
}

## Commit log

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2012-11-26 added empty eagle file forpcb design
    [hexasense.brd, hexasense.sch]
2012-11-26 added holes and keepout for hexabus module
    [hexasense.brd]
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2012-11-29 seperate power supply board
    [power.sch]
2012-11-30 measurement amplifier and low voltage transformation
    [hexasense.brd, hexasense.sch, power.brd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]
2012-11-30 removed measurement amplifier from hexasense board
    [hexasense.brd, hexasense.sch]
2012-11-30 rough placement of parts on pcb
    [power.brd, power.sch]
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2012-12-03 finalized a rough layout
    [power.brd]
2012-12-13 more labels, replaced drills
    [power.brd, power.sch]
2012-12-13 unused pins of RJ45 to GND
    [power.brd, power.sch]
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2012-12-17 added DIL40 socket for hexabus
    [hexasense.brd, hexasense.sch]
2012-12-17 added red, green and blue LEDs. Changed PCB orientation and dimensions
    [hexasense.brd, hexasense.sch]
2012-12-18 placed LEDs on PCB
    [hexasense.brd]
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2012-12-18 redone humidity sensor package
    [hexasense.brd, hexasense.sch]
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2012-12-18 further rearrangement of LEDs, some routing
    [hexasense.brd]
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2013-01-04 added LED driver chip
    [hexasense.brd, hexasense.sch]
2013-01-04 added push buttons and completed schematic for LED driver
    [hexasense.brd, hexasense.sch]
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2013-01-07 switched to Autodesk Inventor for enclosure design
    [Enclosure-bottom.ipt, config.scad, main.scad]
2013-01-07 new design, several components (used derive)
    [Enclosure-bottom.0001.ipt, Enclosure-bottom.ipt, PCB-Model.0001.ipt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]
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2013-01-09 complete redesign.
    [PCB-Model.ipt, Unterschale.ipt, enclosure1.ipt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]
2013-01-09 redesign completed (except for screw head)
    [Assembly1.iam, Oberschale.ipt, PCB-Model.0001.ipt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]
2013-01-10 changed screw to self-tapping DIN 7981
    [Assembly1.iam, Oberschale.ipt, Unterschale.ipt]
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2013-01-11 removed +12V from RJ45 connector
    [hexasense.brd, hexasense.sch]
2013-01-11 new position for the push buttons. therefore a lot of rearanging
    [hexasense.brd, hexasense.sch]
2013-01-11 minor tweaks, 3mm thickness for all walls.
    [Assembly1.ipn, Oberschale.ipt, Unterschale.ipt]
2013-01-11 moved to power_board subdirectory
    [Assembly1.iam, Assembly1.ipn, Enclosure-bottom.0001.ipt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]
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2013-01-11 first components of sense enclosure
    [Assembly1.iam, frontplatte.ipt, pushbutton.ipt]
2013-01-11 update of STL files.
    [Oberschale.stl, Unterschale.stl]
2013-01-14 changed placement of buttons and leds. Did the necessary rerouting. Added a version number.
    [hexasense.brd, hexasense.sch]
2013-01-14 fixed overlap. moved wires away from milling
    [hexasense.brd]
2013-01-14 schraubendim. korrigiert, ausschnitte vergroessert
    [Oberschale.ipt, Oberschale.stl, Unterschale.ipt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]
2013-01-14 implemented a simple PCB model.
    [PCB-Model.ipt]
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2013-01-15 replaced some parts. rearranged parts
    [power.brd, power.sch]
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2013-01-16 Changed outer distance to 6mm. Fixes #2
    [power.brd]
2013-01-18 added capacitor for volage regulator. Fixing #9
    [power.brd, power.sch]
2013-01-18 basic outline of base component defined.
    [Assembly1.iam, PCB-Model.ipt, Unterschale.ipt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]
2013-01-21 fixes #13
    [hexasense.brd, hexasense.sch]
2013-01-21 incresed drill size for humidity sensor. Fixes #11
    [hexasense.brd, hexasense.sch]
2013-01-21 changed LM324 for a working footprint
    [power.brd, power.sch]
2013-01-21 cleanup at RJ45 connector, finalized LM324
    [power.brd, power.sch]
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2013-01-21 preliminary placement of new parts. ripup *
    [power.brd, power.sch]
2013-01-22 corrected some wiring errors around the measuring amp
    [power.brd, power.sch]
2013-01-22 added 2nd temperature signal to schematic
    [hexasense.brd, hexasense.sch]
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2013-01-22 routing of 2nd temperature signal and pullups
    [hexasense.brd, hexasense.sch]
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2013-01-24 changed LED resistors to more fitting values
    [hexasense.brd, hexasense.sch]
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2013-01-29 fixed distance bug.
    [frontplatte.ipt]
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2013-01-30 moved LED driver to frint side (issue #20); included hexabus pairing button (issue #21)'; duplicated footprint of humidity sensor (issue #22)
    [hexasense.brd, hexasense.sch]
2013-01-30 repositioned hexabus module. fixes #23
    [hexasense.brd]
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2013-01-31 added HYT271 humidity sensor
    [hexasense.brd, hexasense.sch]
2013-01-31 resolved inconsistency between board and schematic
    [hexasense.brd, hexasense.sch]
2013-01-31 loch fuer kabeldurchfuehrung hinzugefuegt
    [base.ipt]
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2013-01-31 updated stl export files.
    [base.stl, pushbutton.stl]
2013-01-31 changed VDD for LEDs to +5V
    [hexasense.sch]
2013-01-31 changed LED from 0805 to 5mm THT
    [hexasense.brd, hexasense.sch]
2013-02-01 added 4th LED per color, fixes #27
    [hexasense.brd, hexasense.sch]
2013-02-01 changed pin assignment of RJ45 connector
    [hexasense.brd, hexasense.sch]
2013-02-01 frontplatte for cnc lasercutting
    [frontplatte.dwg]
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2013-02-01 removed ground plane from half the PCB to avoid heating the sensor(s)
    [hexasense.brd]
2013-02-01 increased size of grill rips to prevent slicing fuckups.
    [base.ipt]
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2013-02-04 optimized position of reset button
    [hexasense.brd]
2013-02-04 cleaned up position of led resistors and started routing
    [hexasense.brd]
2013-02-04 some of the sensors were on the wrong side of the PCB
    [hexasense.brd]
2013-02-04 abstraktion des i2c-busses, gruppierung der leds noch unklar (see issue #27)
    [led_driver.c, main.c]
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2013-02-05 added missing wire
    [hexasense.brd]
2013-02-05 added GND around PWM lines leading to LEDs
    [hexasense.brd]
2013-02-05 updated RJ45 connector to new pin assignment
    [power.brd, power.sch]
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2013-02-05 set the distance case - PCB as defined in #2
    [power.brd]
2013-02-06 introduced supersampling - currently untested! fixes #29, fixes #30
    [adc.c]
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2013-02-06 enabled -Werror compiler flag, fixed errors that have been warnings before.
    [adc.c, main.c]
2013-02-06 implemented proper DHT22 error reporting.
    [main.c]
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2013-02-06 bend wires in 45 deg angle
    [hexasense.brd]
2013-02-06 removed unneeded GND polygon
    [hexasense.brd]
2013-02-07 added 100nF capacitors to humidity sensor and LED chip
    [hexasense.brd, hexasense.sch]
2013-02-07 added pin1 info for led chip
    [hexasense.brd]
2013-02-07 use all pins of the buttons
    [hexasense.brd, hexasense.sch]
2013-02-07 changed pin1 info for led chip to pass DRC
    [hexasense.brd]
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2013-02-07 changed even more routing
    [hexasense.brd]
2013-02-07 preliminary placement and routing
    [power.brd, power.sch]
2013-02-07 now passing the DRC
    [power.brd, power.sch]
2013-02-07 arranged position of testpads to multiples of 2.54
    [power.brd]
2013-02-07 cleaned up placement print
    [power.brd]
2013-02-07 changed testpads to THT
    [power.brd, power.sch]
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2013-02-26 up-to-date export of STLs (already rotated)
    [base.stl, pushbutton.stl]
2013-02-28 changed cooling ribs to cooling holes
    [base.ipt]
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2013-03-06 cutouts for components added.
    [Unterschale2.ipt, Unterschale2.stl]
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2013-05-03 now using a real footprint for the epaper display. work in progress
    [hexasense.brd, hexasense.sch]
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2013-05-15 added missing wires
    [hexasense.brd, hexasense.sch]
2013-06-14 added reset and SCLK line for flash chip
    [hexasense.brd, hexasense.sch]
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
